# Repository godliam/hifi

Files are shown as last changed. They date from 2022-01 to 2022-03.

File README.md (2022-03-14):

# Hack实验室 HiFi耳放
原作者: Hack实验室 apollo  
Forked from: [hack-apollo](https://github.com/hack-apollo)  

## Bug fix: 
### V1.3: 
- 修复了左右声道相反的问题
    - 优化了6.35mm元件库图，使其更接近真实情况
    - 修正了主工程原理图
    - 修正了主工程中输出至6.35mm耳机接口的线路，重新生成了Geber
    - 修正了后面板左右声道标志，重新生成后面板Geber

By: godliam 2022.01.25

## License
Hack Audio Spectrum is a free download and may be used, modified, evaluated and distributed without charge provided the user adheres to version three of the GNU General Public License (GPL) and does not remove the copyright notice or this text. The GPL V3 text is available on the gnu.org web site.

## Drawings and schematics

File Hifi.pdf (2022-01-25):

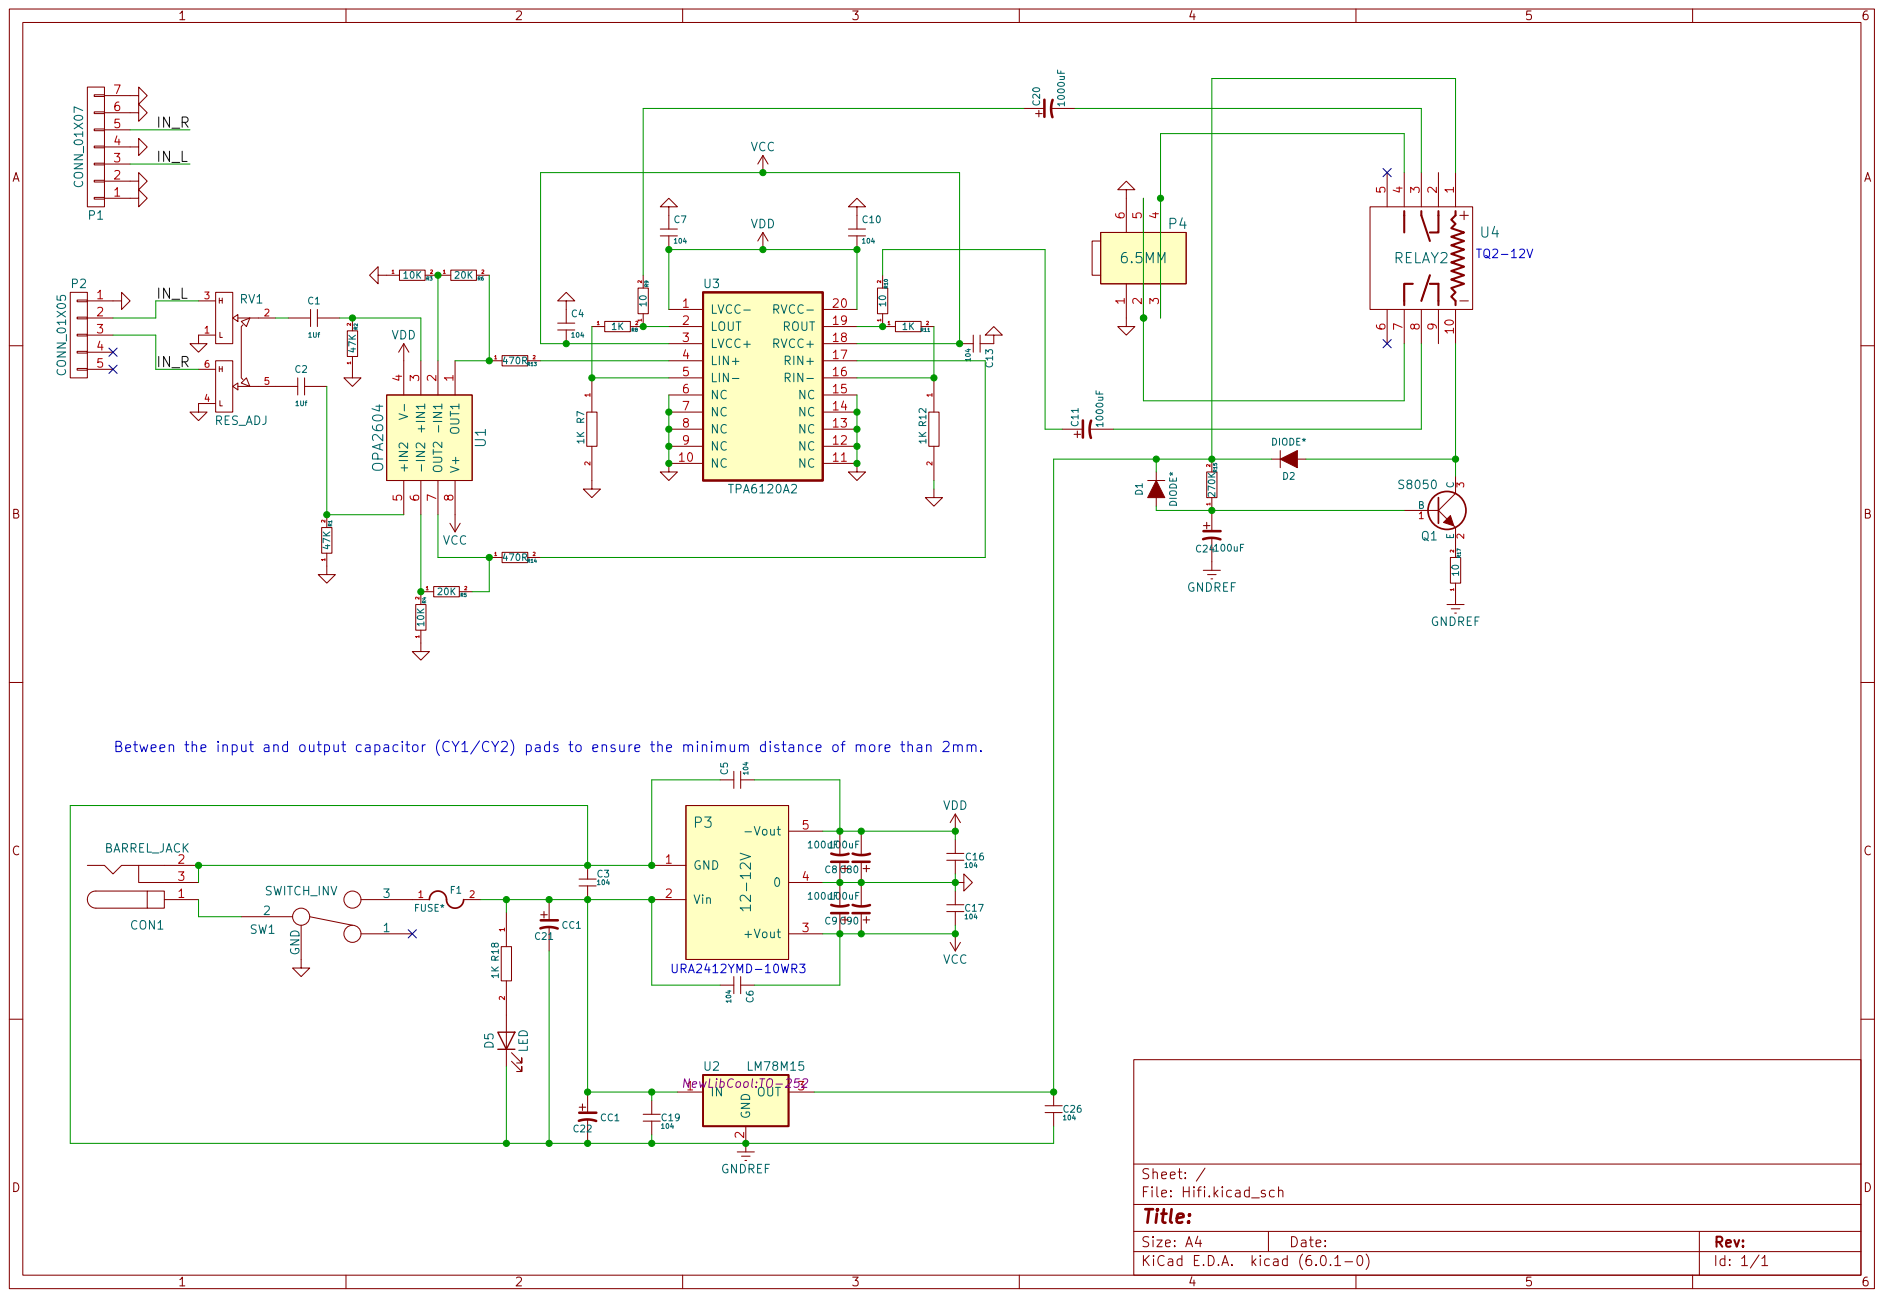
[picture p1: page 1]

1 2 R12 1K LVCC- 1 NC 10 NC 11 NC 12 NC 13 NC 14 NC 15 RIN- 16 RIN+ 17 RVCC+ 18 ROUT 19 LOUT 2 RVCC- 20

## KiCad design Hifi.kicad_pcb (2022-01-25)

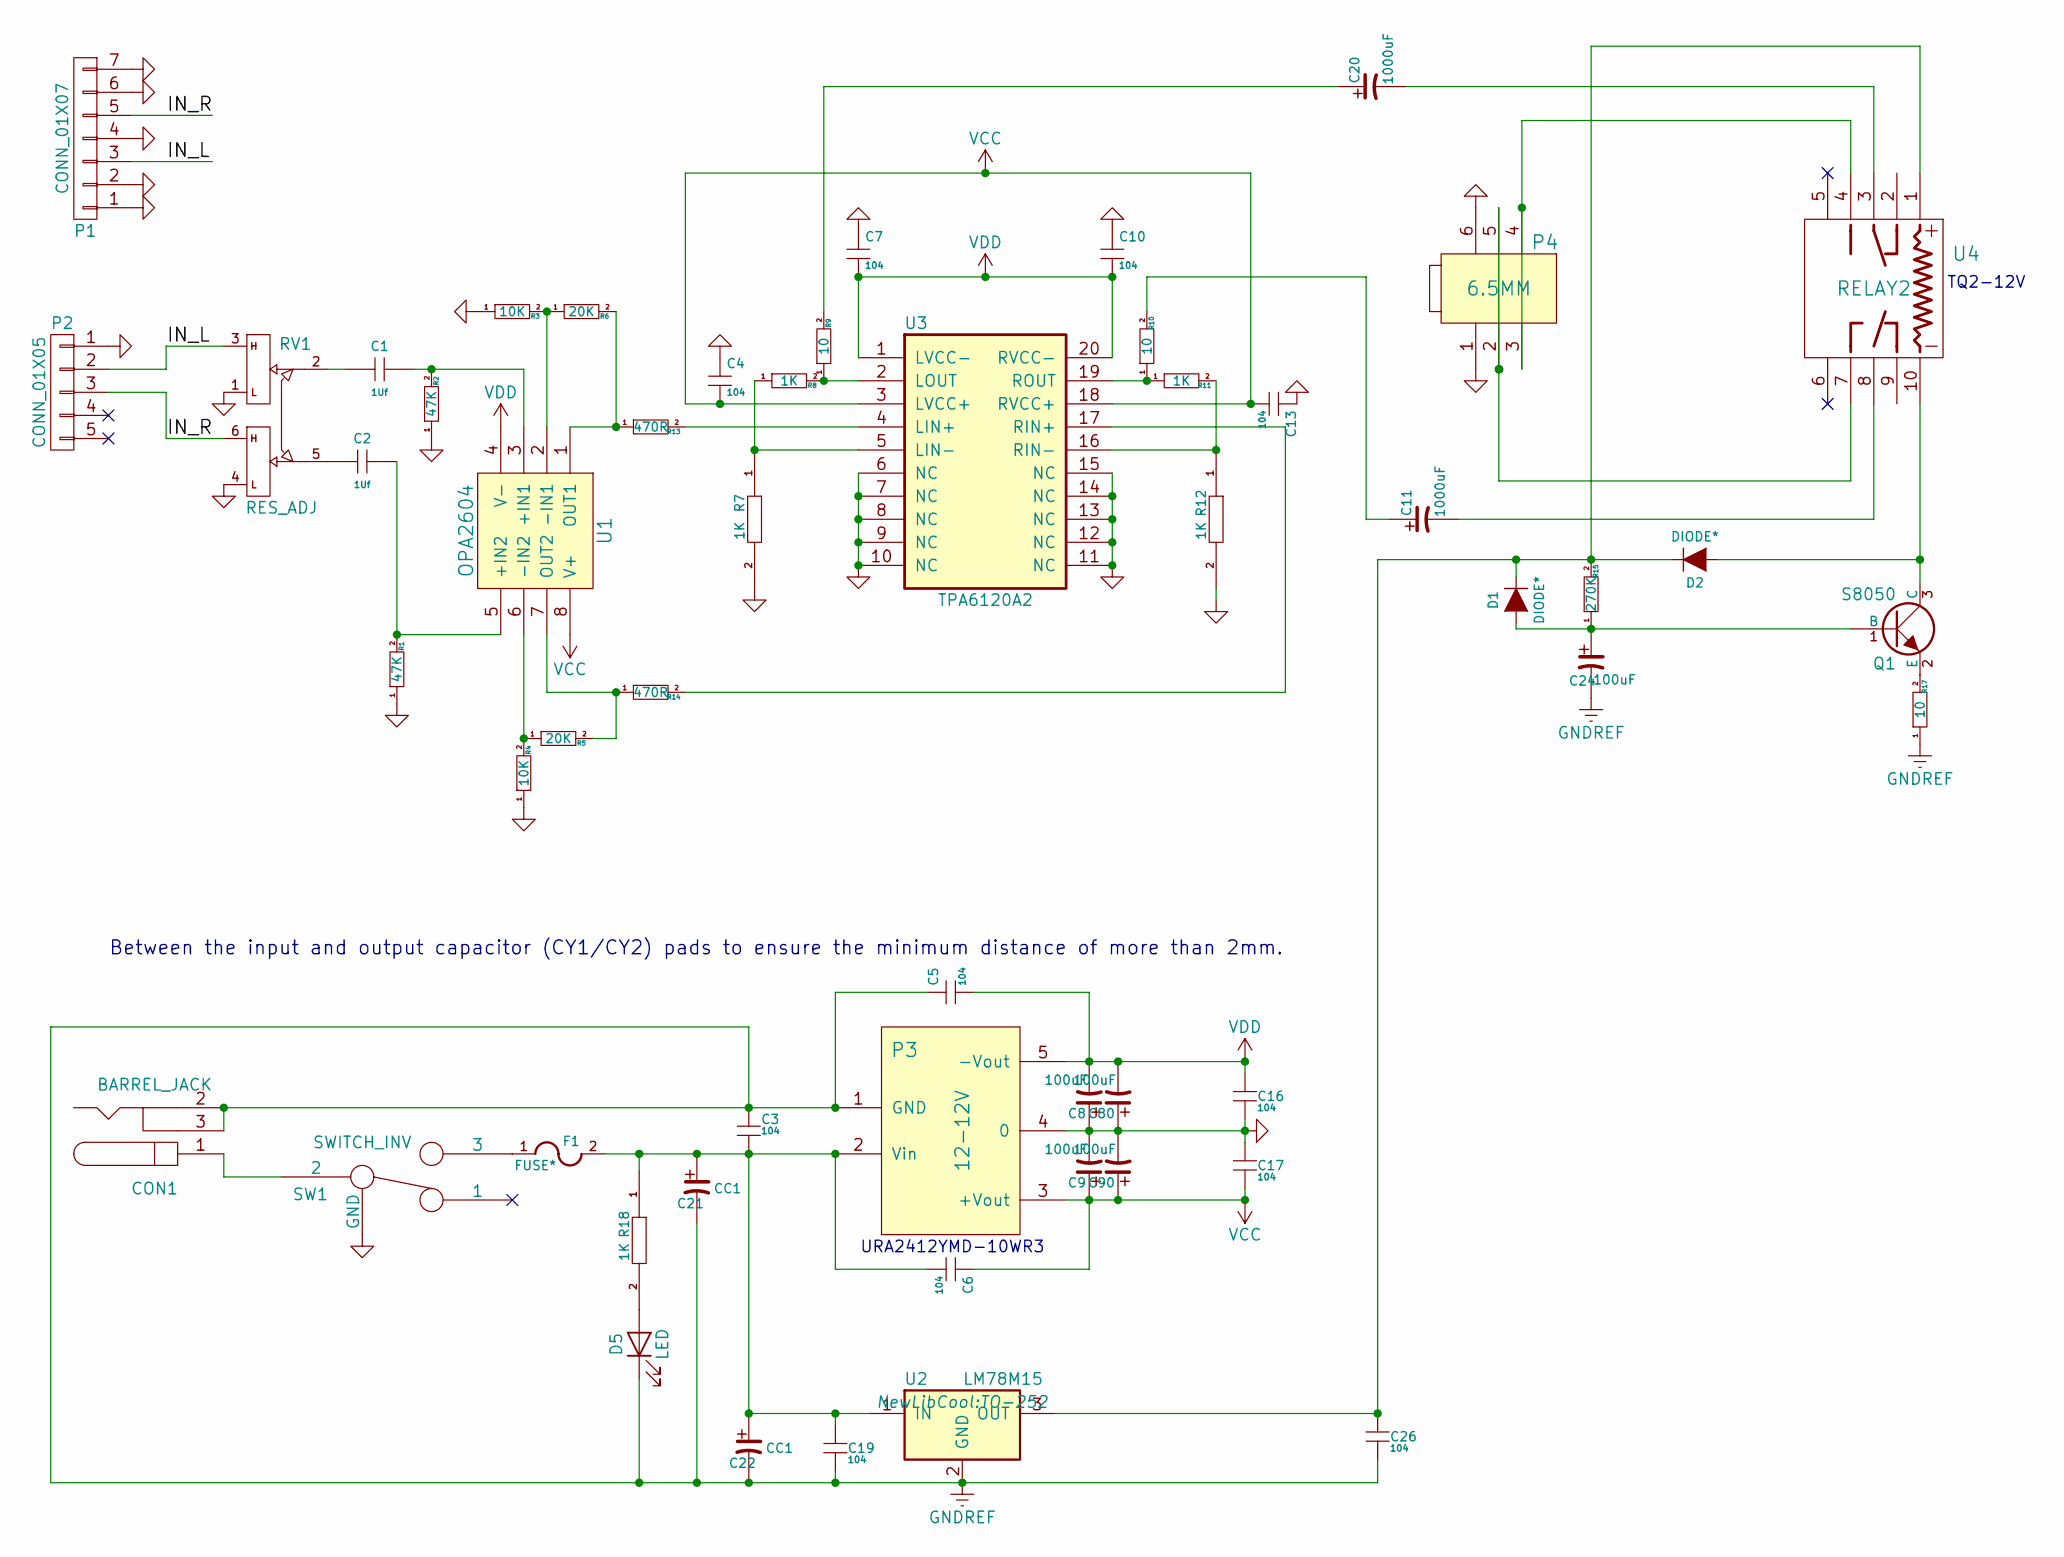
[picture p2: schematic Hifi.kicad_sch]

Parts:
C1, C2: 1Uf; CP_Radial_D5.0mm_P2.50mm
C3, C4, C5, C6, C7, C10, C13, C16, C17, C19, C26: 104; 0805_C
C8, C9, C24, C80, C90: 100uF; c_elec_8x10.5
C11, C20: 1000uF; TantalC_SizeT_3528
C21, C22: CC1; c_elec_8x10.5
CON1: BARREL_JACK; DCDCJACK_ALIM
D1, D2: DIODE*; DO-Diode-214BA
D5: LED; LED-3MM
F1: FUSE*; F_1812
P1: CONN_01X07; Audio_LianHua
P2: CONN_01X05; Audio_3.5mm
P3: 12-12V; DC-DC
P4: 6.5MM; Audio_6.35mm_CN
Q1: S8050; TO-92
R1, R2: 47K; 0805_R
R3, R4: 10K; 0805_R
R5, R6: 20K; 0805_R
R7, R8, R11, R12, R18: 1K; 0805_R
R9, R10, R17: 10; 0805_R
R13, R14: 470R; 0805_R
R15: 270K; 0805_R
RV1: RES_ADJ; ADJ_RES
SW1: SWITCH_INV; SWITCH_Toggle
U1: OPA2604; DIP-8_NEW
U2: LM78M15; TO-252
U3: TPA6120A2; SOIC-20_7.5x12.8mm_Pitch1.27mm
U4: RELAY2; RELAY_A5W

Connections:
/IN_L: P1.3, P2.2, RV1.3
/IN_R: P1.5, P2.3, RV1.6
GND: C4.1, C7.1, C8.1, C9.2, C10.1, C13.1, C16.2, C17.1, C80.1, C90.2, P1.1, P1.2, P1.4, P1.6, P1.7, P2.1, P3.4 (0), P4.1, P4.6, R1.1, R2.1, R3.1, R4.1, R7.2, R12.2, RV1.1, RV1.4, SW1.0 (GND), U3.6 (NC), U3.7 (NC), U3.8 (NC), U3.9 (NC), U3.10 (NC), U3.11 (NC), U3.12 (NC), U3.13 (NC), U3.14 (NC), U3.15 (NC)
GNDREF: C3.1, C5.1, C19.2, C21.2, C22.2, C24.2, C26.2, CON1.2, CON1.3, D5.1 (K), P3.1 (GND), R17.1, U2.2 (GND)
unnamed: C1.1, RV1.2
unnamed: C1.2, R2.2, U1.3 (+IN1)
unnamed: C2.1, RV1.5
unnamed: C2.2, R1.2, U1.5 (+IN2)
unnamed: C11.1, R10.2
unnamed: C11.2, U4.8
unnamed: C3.2, C6.2, C19.1, C21.1, C22.1, F1.2, P3.2 (Vin), R18.1, U2.1 (IN)
unnamed: C20.1, R9.2
unnamed: C20.2, U4.3
unnamed: C24.1, D1.1 (A), Q1.1 (B), R15.1
unnamed: C26.1, D1.2 (K), D2.2 (K), R15.2, U2.3 (OUT), U4.1
unnamed: CON1.1, SW1.2
unnamed: D2.1 (A), Q1.3 (C), U4.10
unnamed: D5.2 (A), R18.2
unnamed: F1.1, SW1.3
unnamed: P4.2, P4.5, U4.7
unnamed: P4.3, P4.4, U4.4
unnamed: Q1.2 (E), R17.2
unnamed: R3.2, R6.1, U1.2 (-IN1)
unnamed: R4.2, R5.1, U1.6 (-IN2)
unnamed: R7.1, R8.1, U3.5 (LIN-)
unnamed: R8.2, R9.1, U3.2 (LOUT)
unnamed: R10.1, R11.1, U3.19 (ROUT)
unnamed: R11.2, R12.1, U3.16 (RIN-)
unnamed: R6.2, R13.1, U1.1 (OUT1)
unnamed: R13.2, U3.4 (LIN+)
unnamed: R5.2, R14.1, U1.7 (OUT2)
unnamed: R14.2, U3.17 (RIN+)
VCC: C4.2, C6.1, C9.1, C13.2, C17.2, C90.1, P3.3 (+Vout), U1.8 (V+), U3.3 (LVCC+), U3.18 (RVCC+)
VDD: C5.2, C7.2, C8.2, C10.2, C16.1, C80.2, P3.5 (-Vout), U1.4 (V-), U3.1 (LVCC-), U3.20 (RVCC-)

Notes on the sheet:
URA2412YMD-10WR3
TQ2-12V
Between the input and output capacitor (CY1/CY2) pads to ensure the minimum distance of more than 2mm.

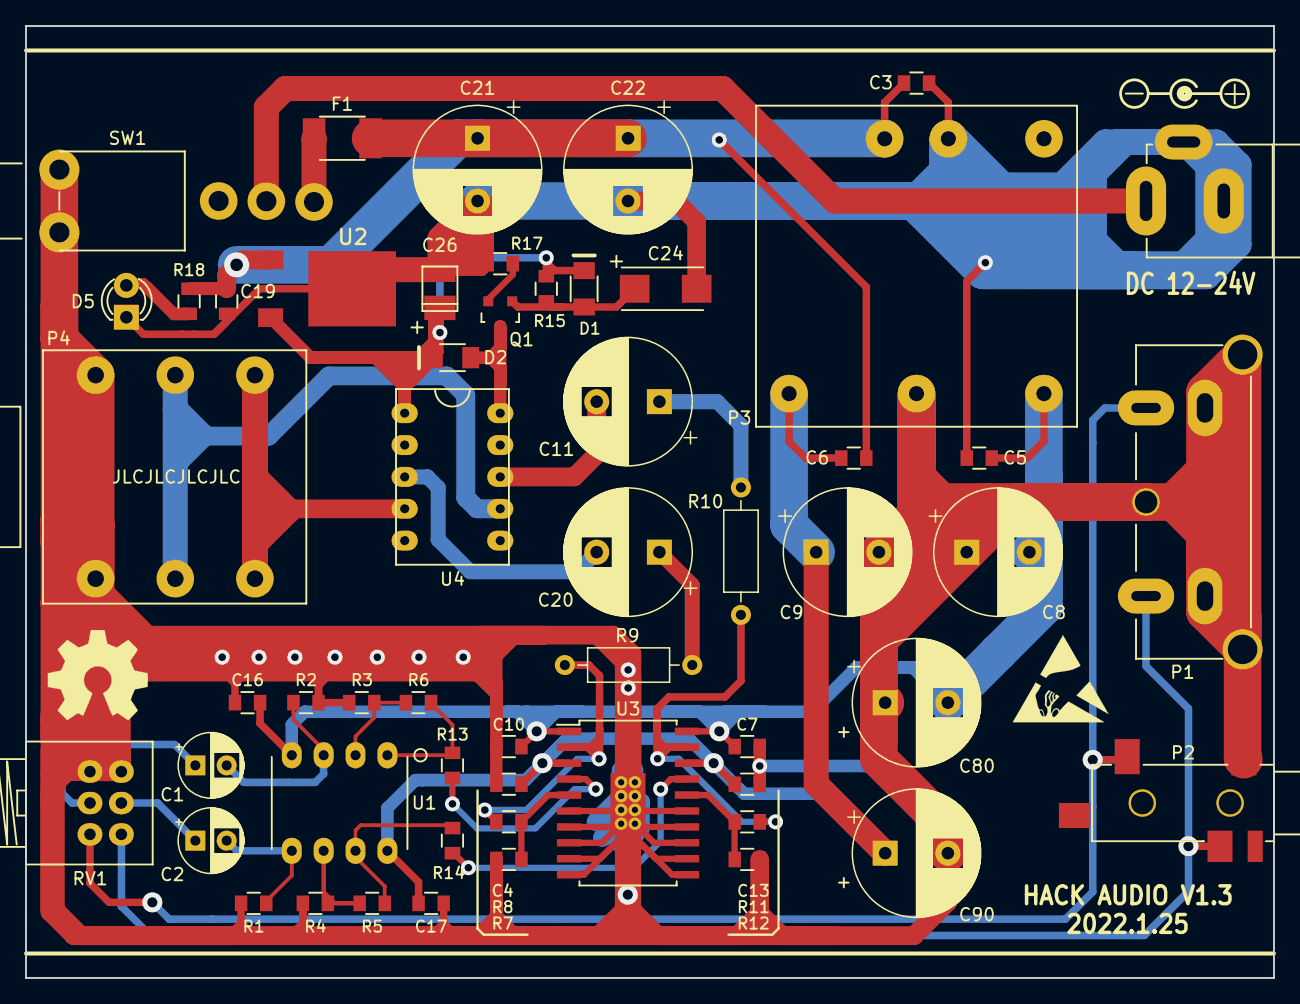
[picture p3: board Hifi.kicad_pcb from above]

Board: 2 copper layers, 99.5 x 75.9 mm, 55 parts (0 on the bottom side), 34 nets.
